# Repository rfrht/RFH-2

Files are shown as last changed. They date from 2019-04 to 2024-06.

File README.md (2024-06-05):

# RFH-2
Remote Control unit compatible with most modern Yaesu radios. Includes Schematics, Gerber Files and Board Design.

## What is this?
This is a remote control that is compatible with most modern and recent Yaesu radios. It mimicks the same functionality of [Yaesu FH-2](http://lmgtfy.com/?q=yaesu+fh-2) remote control, at a fraction of the cost ane with a enormous cool factor: YOU CAN ACTUALLY BUILD IT!

Check how [Jim N5JGE](https://www.qrz.com/db/N5JGE) actually built something [**really nifty**](https://github.com/jgedmond/RFH-2/commit/793899766d5572a83a48a860f2a84d2ef02e2b0a) without the need of an enclosure for the board!

## How does the board looks like?
This is the board layout in its full glory (slightly changed from FH-2, because... usability++):

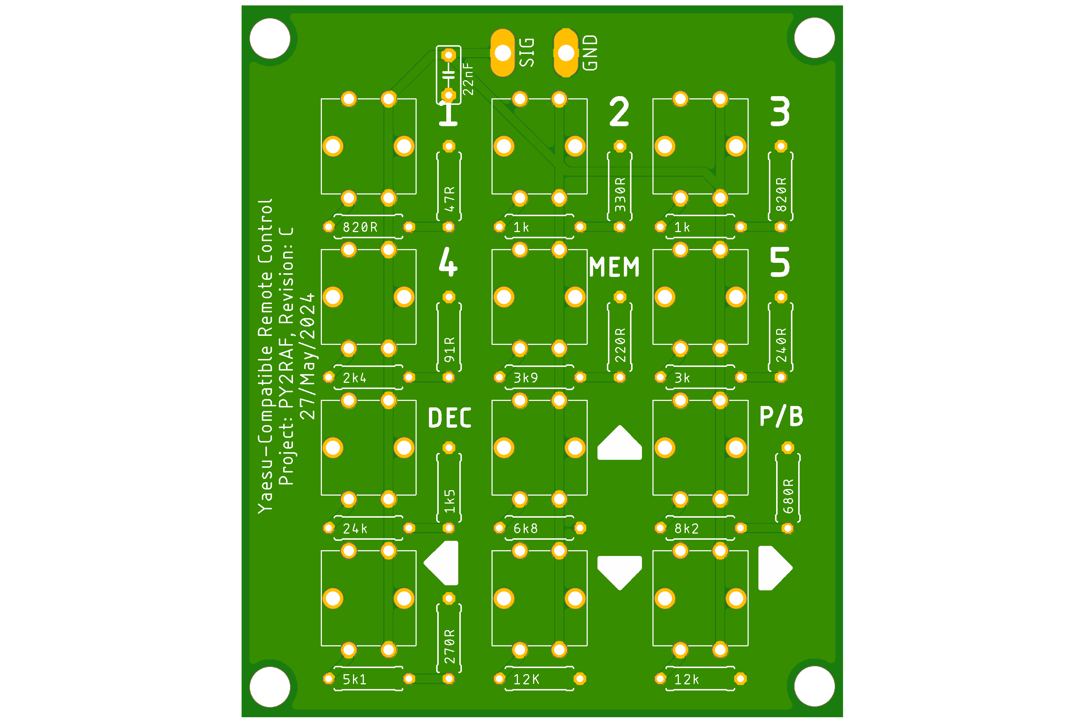
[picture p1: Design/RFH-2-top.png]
RFH-2


## Did you prototype it?
Yup. Picture below:
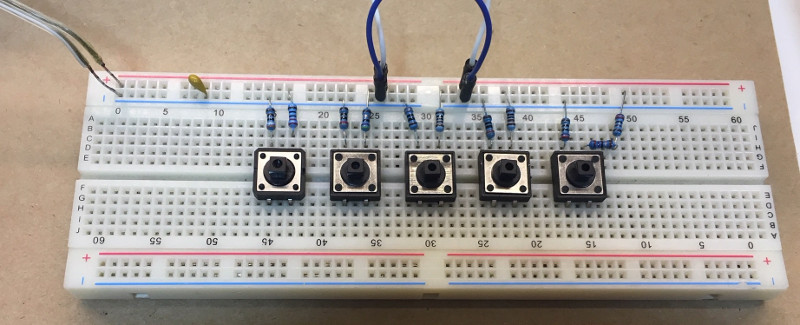
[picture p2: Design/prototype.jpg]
RFH-2 Prototype


## What are the compatible radios?
Yaesu FT-991, FT-991A, FT-950, FTDX-9000, FTDX-5000, FTDX-3000, FT-2000, FTDX-1200, FT-1000MP

## Nice, I liked it! How do I get one?
1. Download the Gerber [.zip file](https://github.com/rfrht/RFH-2/raw/master/Design/RFH-2-gerbers.zip)

2. Send the Gerber ZIP to any PCB Print Service. I have used [JLCPCB](https://jlcpcb.com/quote), they are dead cheap - Paid $2 for 5 boards

3. Buy the switches and the resistors. The most critical part here are the switches: The board has the footprints for this specific switch, which is [Digikey Part EG6117-ND](https://www.digikey.com/products/en?keywords=eg6117-nd). The Resistors and Capacitor are through-hole and the values are in the Schematic.

4. How do I wire it? For wiring, wire the tip of a standard 3-pin audio plug and the `GND` part of the plug. Leave the center floating.

Of course you can also download [Eagle 9](https://www.autodesk.com/products/eagle/free-download) and play with the schematics and PCB layout in [Design](/Design) folder.

## CHANGELOG

### Revision C (May 27, 2024)
* Fixed the flipped Down arrow and F/B button reported in [Issue 1](https://github.com/rfrht/RFH-2/issues/1) by jgedmond - thank you!

### Revision B (Jun 8, 2019)
* Fixed the push-button pinout
* Now makes extensive use of ground plane
* Rewired the board
* Larger holes, suitable for a screw, with symmetrical holes at the board edges
* A through-the-hole pad for the signal input
* Added a few centimeters more to accomodate the $ABOVE changes
* And that's it folks!

### Revision A (Apr 28, 2019)
* Initial release

73s de PY2RAF.

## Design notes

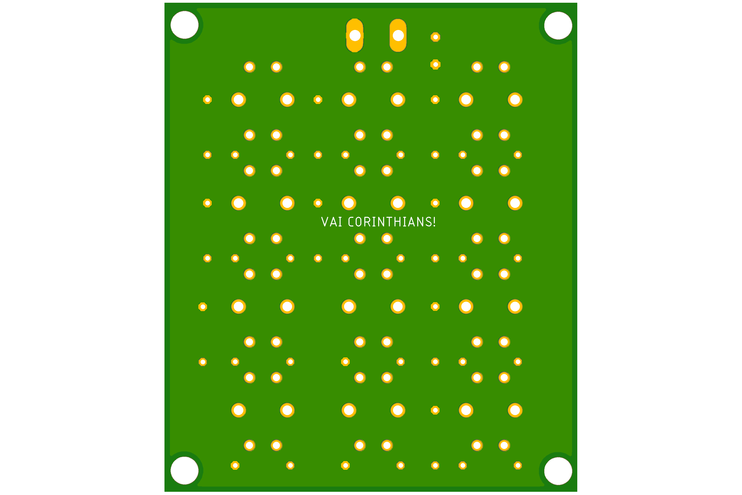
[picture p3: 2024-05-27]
Design/RFH-2-bottom.png

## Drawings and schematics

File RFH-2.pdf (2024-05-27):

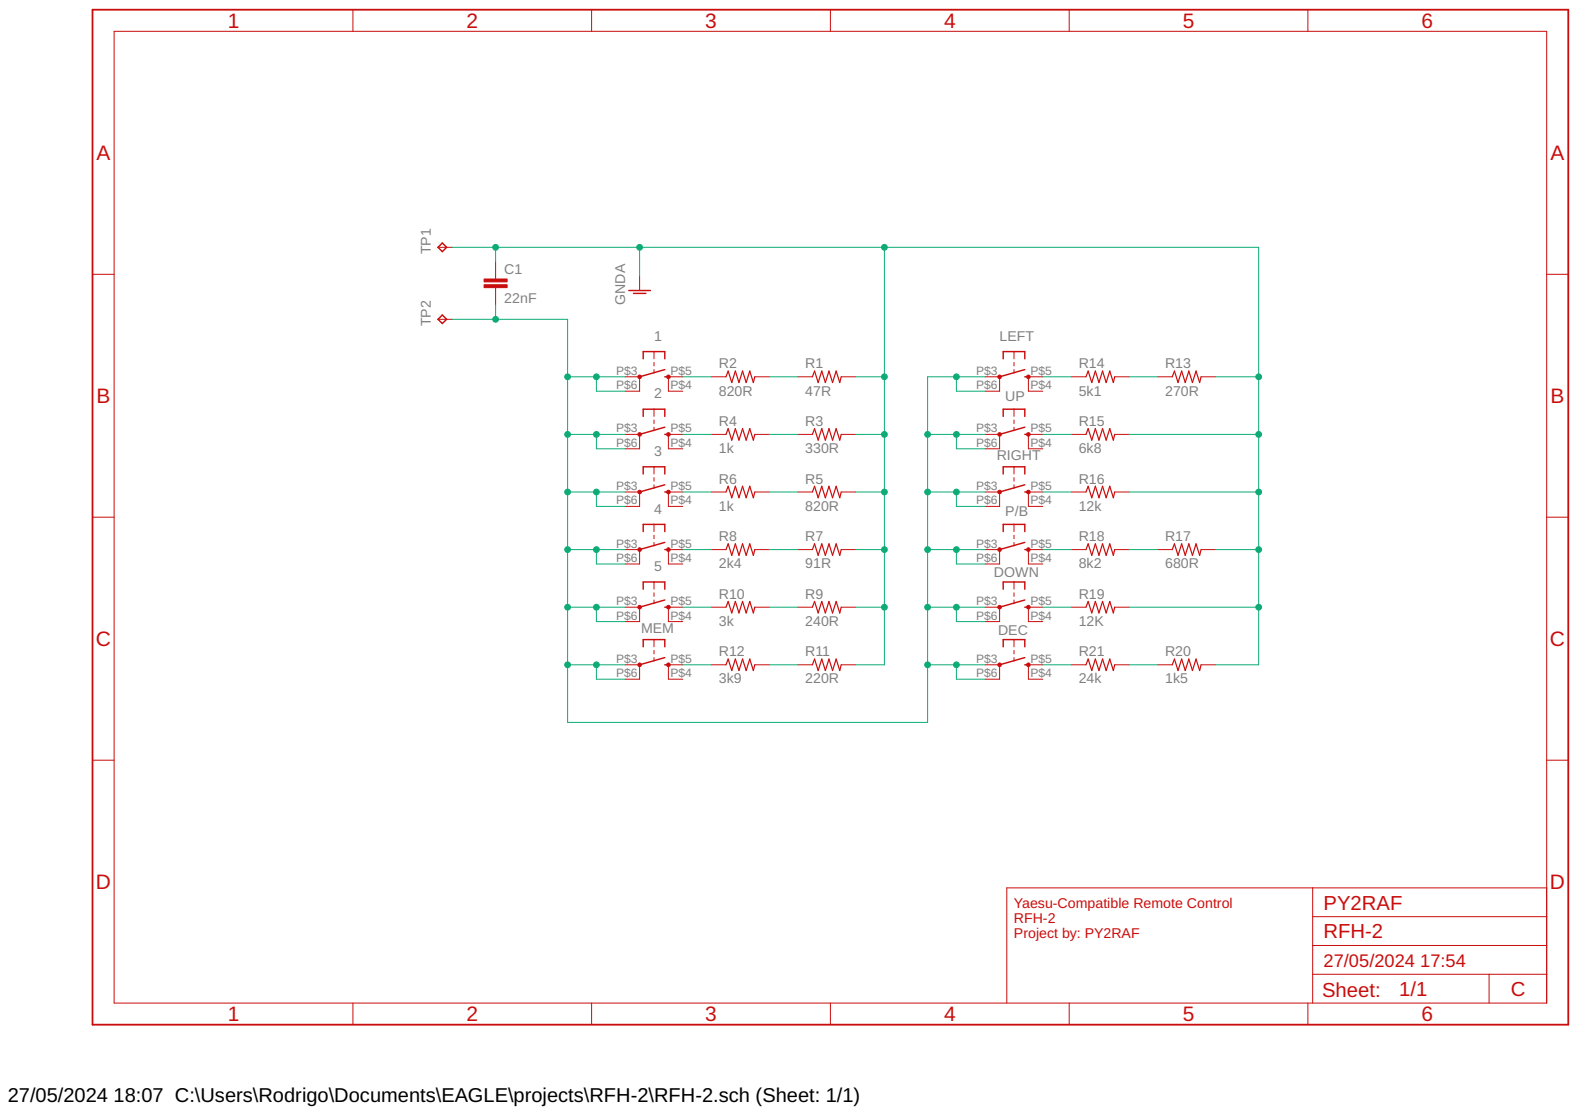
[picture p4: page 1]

Yaesu-Compatible Remote Control
RFH-2
Project by: PY2RAF

27/05/2024 18:07 C:\Users\Rodrigo\Documents\EAGLE\projects\RFH-2\RFH-2.sch (Sheet: 1/1)

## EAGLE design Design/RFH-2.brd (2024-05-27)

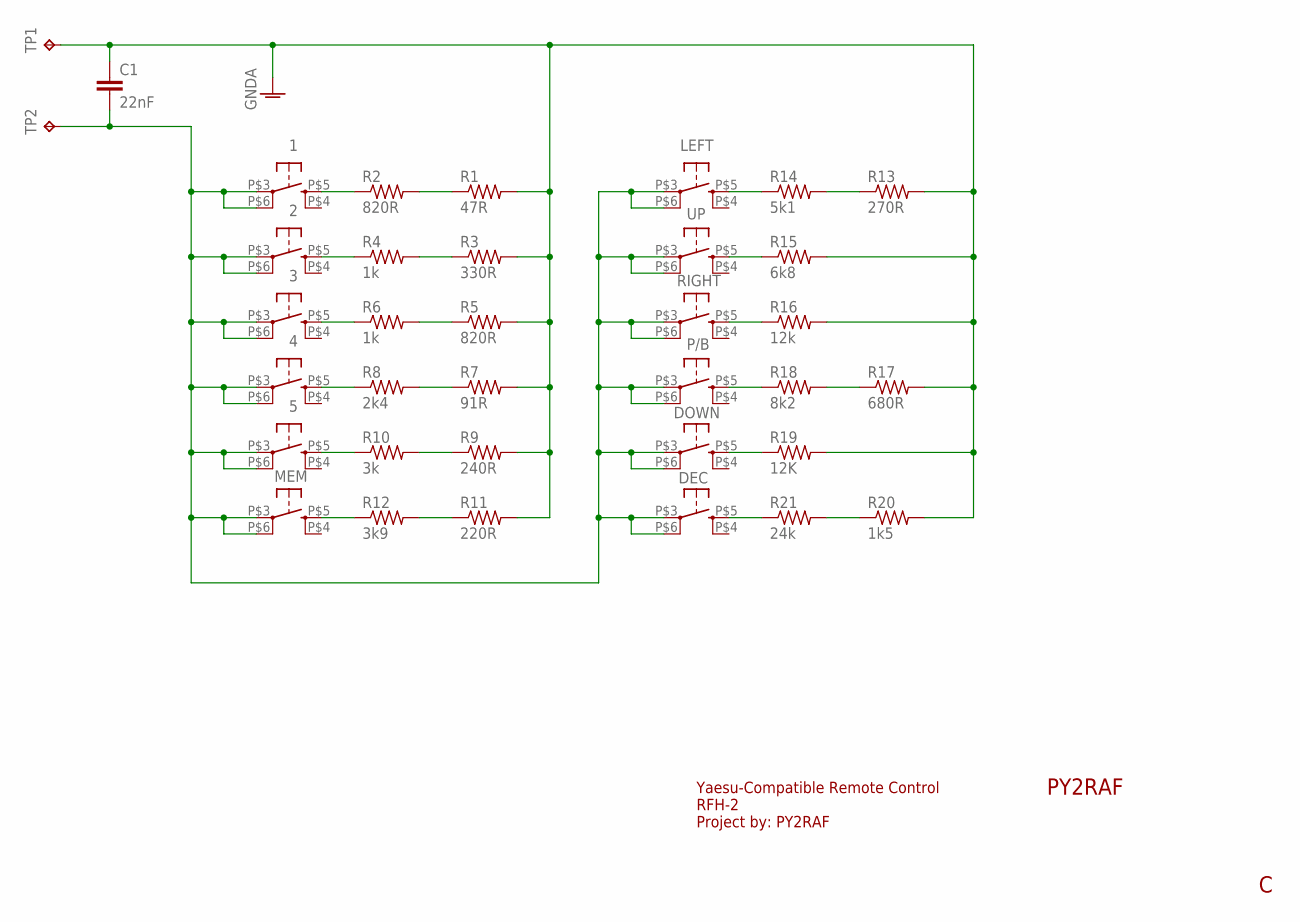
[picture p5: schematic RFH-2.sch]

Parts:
1, 2, 3, 4, 5: TL6300-SPST; TL6300
C1: 22nF; C5B3
DEC: TL6300-SPST; TL6300
DOWN: TL6300-SPST; TL6300
LEFT: TL6300-SPST; TL6300
MEM: TL6300-SPST; TL6300
P/B: TL6300-SPST; TL6300
R1: 47R; 0309/10
R2, R5: 820R; 0309/10
R3: 330R; 0309/10
R4, R6: 1k; 0309/10
R7: 91R; 0309/10
R8: 2k4; 0309/10
R9: 240R; 0309/10
R10: 3k; 0309/10
R11: 220R; 0309/10
R12: 3k9; 0309/10
R13: 270R; 0309/10
R14: 5k1; 0309/10
R15: 6k8; 0309/10
R16: 12k; 0309/10
R17: 680R; 0309/10
R18: 8k2; 0309/10
R19: 12K; 0309/10
R20: 1k5; 0309/10
R21: 24k; 0309/10
RIGHT: TL6300-SPST; TL6300
TP1, TP2: TPPAD1-20Y; P1-20Y
UP: TL6300-SPST; TL6300

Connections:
GNDA: C1.1, R1.2, R3.2, R5.2, R7.2, R9.2, R11.2, R13.2, R15.2, R16.2, R17.2, R19.2, R20.2, TP1.TP
unnamed: 1.P$3, 1.P$6 (P1), 2.P$3, 2.P$6 (P1), 3.P$3, 3.P$6 (P1), 4.P$3, 4.P$6 (P1), 5.P$3, 5.P$6 (P1), C1.2, DEC.P$3, DEC.P$6 (P1), DOWN.P$3, DOWN.P$6 (P1), LEFT.P$3, LEFT.P$6 (P1), MEM.P$3, MEM.P$6 (P1), P/B.P$3, P/B.P$6 (P1), RIGHT.P$3, RIGHT.P$6 (P1), TP2.TP, UP.P$3, UP.P$6 (P1)
unnamed: R17.1, R18.2
unnamed: LEFT.P$5 (S), R14.1
unnamed: R15.1, UP.P$5 (S)
unnamed: R16.1, RIGHT.P$5 (S)
unnamed: P/B.P$5 (S), R18.1
unnamed: DOWN.P$5 (S), R19.1
unnamed: 1.P$5 (S), R2.1
unnamed: DEC.P$5 (S), R21.1
unnamed: 2.P$5 (S), R4.1
unnamed: 3.P$5 (S), R6.1
unnamed: 4.P$5 (S), R8.1
unnamed: 5.P$5 (S), R10.1
unnamed: MEM.P$5 (S), R12.1
unnamed: R13.1, R14.2
unnamed: R1.1, R2.2
unnamed: R3.1, R4.2
unnamed: R5.1, R6.2
unnamed: R7.1, R8.2
unnamed: R9.1, R10.2
unnamed: R11.1, R12.2
unnamed: R20.1, R21.2

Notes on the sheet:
Yaesu-Compatible Remote Control RFH-2 Project by: PY2RAF
PY2RAF

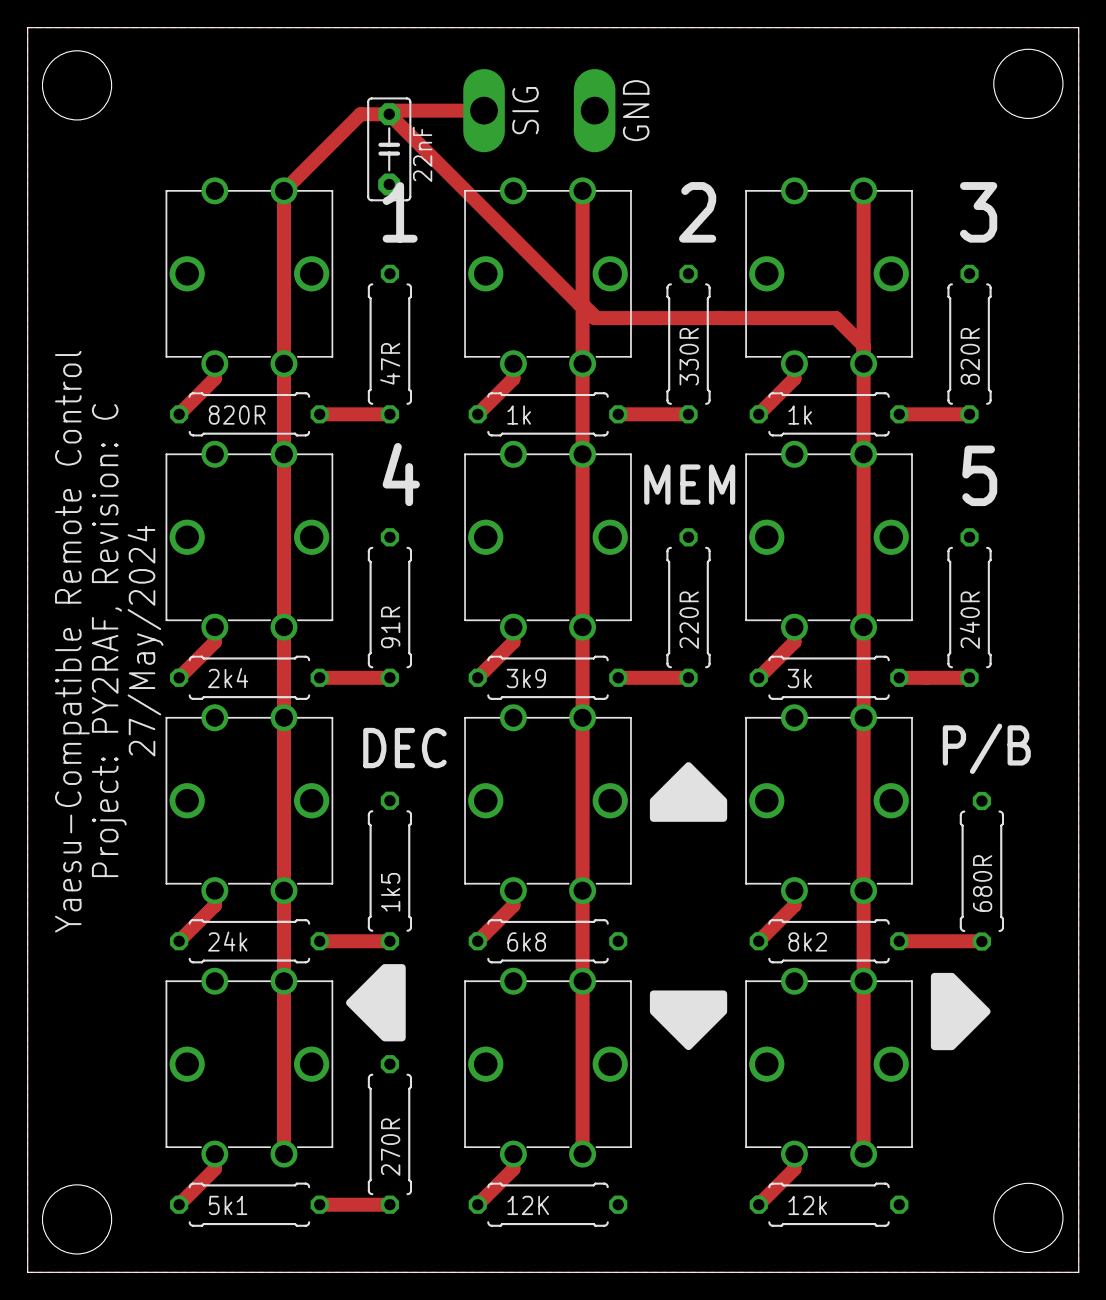
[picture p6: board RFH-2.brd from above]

Board: 2 copper layers, 76.0 x 90.0 mm, 36 parts (0 on the bottom side), 23 nets.

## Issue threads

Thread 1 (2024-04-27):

P/B and Down Arrows Mixed Up

jgedmond, 2024-04-27:
The resistance values for the P/B and Down Arrow switches are reversed.  P/B is triggered by 16.9k Ohms and Down Arrow is triggered by 12k Ohms.  To fix this, I had to solder the 13k Ohm and 3.9k Ohm resistors in series and mount them in the "12k Ohm" holes below the P/B switch.  Secondly, I soldered a 12k Ohm resistor in the "13k Ohm" position below the Down Arrow switch and a short in the "3.9k Ohm" position to the right of the Down Arrow switch.

rfrht, 2024-05-27:
Thank you **very much** for pointing it, @jgedmond ! Fixed, as per your report.

jgedmond, 2024-05-28:
Thank you, enjoying the circuit.  I made top and bottom boards to make a "sandwich" for protection of the main board.  Waiting for 3/16" spacers to make sure those work.

73, Jim - N5JGE

rfrht, 2024-05-29:
Ensure to send pictures!!!

jgedmond, 2024-05-29:
I am out of town until later this week.  Parts from Digi-Key were delivered today, so I should put it together over the weekend and take pictures.

Closed 2024-05-27.

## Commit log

2019-04-28 Initial commit: Revision A
    [RFH-2.brd, RFH-2.sch]
2019-04-28 Added Prototype picture
2019-04-28 Added Prototype to Readme
2019-06-09 Revision B
    * Fixed the push-button pinout
    * Now makes extensive use of ground plane
    * Rewired the board
    * Larger holes, suitable for a screw, with symmetrical holes at the
    * board edges
    * A through-the-hole pad for the signal input
    * Added a few centimeters more to accomodate the $ABOVE changes
    * And that's it folks!
    [RFH-2.brd, RFH-2.sch]
2024-05-27 Schematic: Fixes #1
    https://github.com/jgedmond pointed a flipped Down Arrow and F/B
    button. Thanks for reporting it!
    [RFH-2.brd, RFH-2.sch]
2024-05-27 Board: Fixed silkscreen missing component values
    [RFH-2.brd]
2024-06-05 Added reference to Jim's board
